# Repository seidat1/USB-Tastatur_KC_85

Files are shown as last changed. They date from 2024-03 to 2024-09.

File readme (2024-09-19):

#USB to KC 85

Dies ist ein Adapter, um eine USB-Tastatur an einen KC 85/2..5 anzuschließen.
Es ist mit diesem Adapter auch möglich ein Bluethoos-Tastatur zu betreiben.
Am KC 85 ist keine Änderung notwendig. Es werden die Signale der Originaltastatur nachgebildet.
Dies ergibt eine Flexibilität, wie sie bei der bisherigen Tastatur nicht möglich war. Jeder Taste und jeder Tastenkombination kann ein beliebiges Zeichen oder sogar beliebige Zeichenketten mit Steuerzeichen zugeordnet werden.

Grundlage dieses Adapters ist ein WEMOS D1 mini, der einen ESP8266 Mikroprozessor beinhaltet.
Der USB-Anschluss wird mit einem USB-Host Shield realisiert. 

Die Tastatursignale werden per USB an den USB-Host-Adapter gesendet und von dort per SPI an den Mikroprozessor weitergeleitet. Dieser erzeugt dann das Signal der KC-Tastatur und gibt dieses an den Tastaturstecker ab.
Die Tastencodes und Zeichenketten sind in einer Tastaturtabelle hinterlegt. Diese hat folgenden Aufbau:
	# große Buchstaben
	[CharTable]		# char 'A'
	KeyCnt	= 0x02
	CntMask	= 0xFF
	KeyCode	= 0x04
	Strg	= "A"
	.
	.
	.

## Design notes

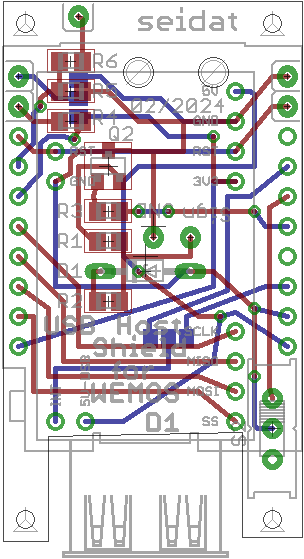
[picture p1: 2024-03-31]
Bilder/Leiterplatte.png

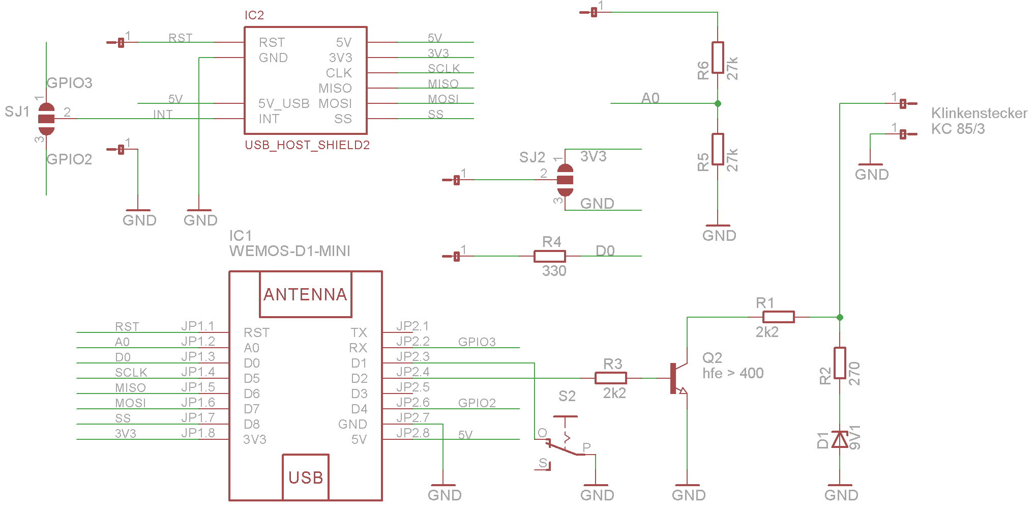
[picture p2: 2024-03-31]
Bilder/Schaltung.png

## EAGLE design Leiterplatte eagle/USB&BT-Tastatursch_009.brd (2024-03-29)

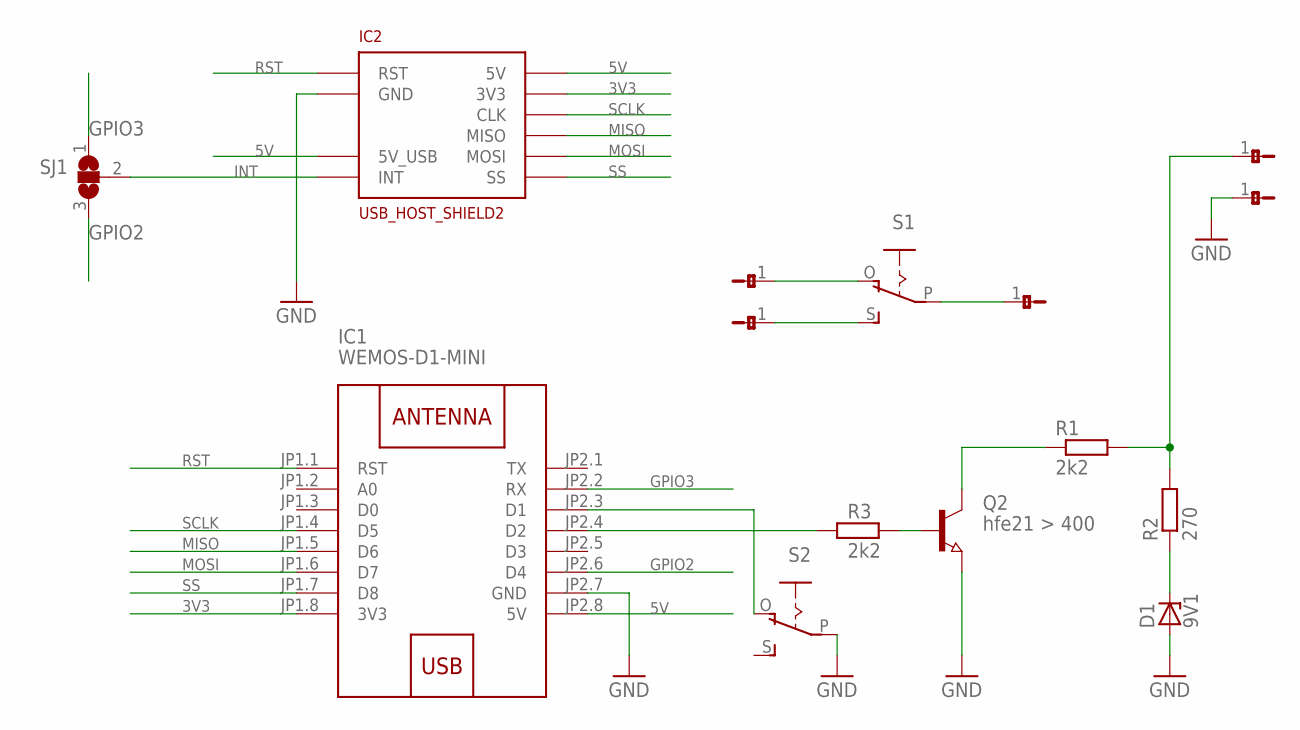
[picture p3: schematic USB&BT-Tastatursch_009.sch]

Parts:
D1: 9V1; DO34Z7
IC1: WEMOS-D1-MINI; WEMOS-D1-MINI_PUR
IC2: USB_HOST_SHIELD2; USB_HOST_SHIELD_2
Q2: hfe21 > 400; SOT23W
R1, R3: 2k2; M0805
R2: 270; M0805
S1, S2: EG1218S; EG1218
SJ1: SJ2WSJ_2B; SJ_2B
U$2, U$3, U$4, U$5, U$6: JP1-1JP1-1C; JP1-1C

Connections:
3V3: IC1.JP1.8 (3V3), IC2.VCC (3V3)
5V: IC1.JP2.8 (5V), IC2.5V, IC2.5V_USB
GND: D1.A, IC1.JP2.7 (GND), IC2.GND, IC2.GND@1 (GND), Q2.3 (E), S2.P, U$3.1
GPIO2: IC1.JP2.6 (D4), SJ1.3
GPIO3: IC1.JP2.2 (RX), SJ1.1
INT: IC2.INT, SJ1.2
MISO: IC1.JP1.5 (D6), IC2.MISO
MOSI: IC1.JP1.6 (D7), IC2.MOSI
unnamed: IC1.JP2.3 (D1), S2.O
unnamed: IC1.JP2.4 (D2), R3.1
unnamed: R1.2, R2.2, U$2.1
unnamed: D1.C, R2.1
unnamed: Q2.2 (C), R1.1
unnamed: S1.P, U$4.1
unnamed: S1.S, U$6.1
unnamed: Q2.1 (B), R3.2
unnamed: S1.O, U$5.1
RST: IC1.JP1.1 (RST), IC2.RST, IC2.RST@1 (RST)
SCLK: IC1.JP1.4 (D5), IC2.CLK
SS: IC1.JP1.7 (D8), IC2.SS

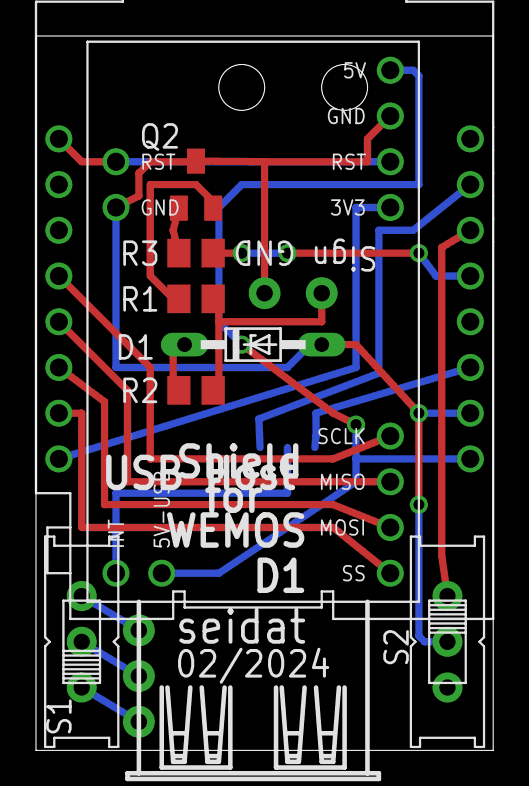
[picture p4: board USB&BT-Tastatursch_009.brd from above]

Board: 2 copper layers, 25.4 x 39.7 mm, 15 parts (1 on the bottom side), 20 nets.

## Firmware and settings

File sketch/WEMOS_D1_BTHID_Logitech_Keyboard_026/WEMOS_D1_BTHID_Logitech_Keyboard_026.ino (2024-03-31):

/*
 * Jona Scheidat
 * 
 * März/2024
 * 
 * 
 * 
 */

#define Schalter D1
#define SWPOS HIGH  // dieser Wert bestimmt, in welcher Schalterposition BT benutzt wird

#include <hidboot.h>
//#include <usbhub.h>
#include <BTHID.h>
#include <SPI.h>
KBDLEDS kleds;
#include "KC85.h"
#include "KeyboardParser.h"

USB     Usb;
//USBHub     Hub(&Usb);
HIDBoot<USB_HID_PROTOCOL_KEYBOARD>    HidKeyboard(&Usb);

BTD Btd(&Usb); // You have to create the Bluetooth Dongle instance like so

/* You can create the instance of the class in two ways */
// This will start an inquiry and then pair with your device - you only have to do this once
// If you are using a Bluetooth keyboard, then you should type in the password on the keypad and then press enter
BTHID bthid(&Btd, PAIR, "0000");


KbdRptParser Prs;


void setup()
{
  Serial.begin( 115200 );
  // initialize digital pin LED_BUILTIN as an output.
  pinMode(LED_BUILTIN, OUTPUT);
  digitalWrite(LED_BUILTIN, HIGH);
  // initialize digital pin D1 as an input.
  pinMode(Schalter, INPUT_PULLUP);
  
  delay(200); // Auszeit für die serielle Schnittstelle
  Serial.println("Start");

  setupKC(); 

  if (Usb.Init() == -1) 
  {
    Serial.println("OSC did not start.");
    while(1==1);
  }
  
  // prüfe die Schalterstellung und initialisiere für BT-Tastatur oder USB-Tastatur
  if (digitalRead(Schalter) == SWPOS)
  { // BT-Tastatur
    bthid.SetReportParser(KEYBOARD_PARSER_ID, &Prs);
    // If "Boot Protocol Mode" does not work, then try "Report Protocol Mode"
    // If that does not work either, then uncomment PRINTREPORT in BTHID.cpp to see the raw report
    bthid.setProtocolMode(USB_HID_BOOT_PROTOCOL); // Boot Protocol Mode
    //bthid.setProtocolMode(HID_RPT_PROTOCOL); // Report Protocol Mode
    Serial.println("Software fuer BT-HID initialisiert");
    KC_PrintString(" Modus:BT\x08\x08\x08\x08\x08\x08\x08\x08\x08\x08\x0A%");
  }
  else
  { // USB-Tastatur
    HidKeyboard.SetReportParser(0, &Prs);
    Serial.println("Software fuer USB-Keyboard initialisiert");
    KC_PrintString(" Modus:USB\x08\x08\x08\x08\x08\x08\x08\x08\x08\x08\x08\x0A%");
  }
}

void loop()
{
  Usb.Task();
}

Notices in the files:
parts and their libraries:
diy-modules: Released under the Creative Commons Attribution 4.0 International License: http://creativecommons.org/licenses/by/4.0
